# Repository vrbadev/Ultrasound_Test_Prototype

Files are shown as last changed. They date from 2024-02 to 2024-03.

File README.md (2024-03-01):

# MRS Project: Ultrasound Test (Prototype)
HW &amp; SW Project for feasibility assessment of accoustic localisation on board of UAVs

## HW Notes
* Project for Altium Designer 24.1.2
* Board power: +5V, fed to regulator AMS1117-3.3 with 3.3V output
* Main MCU: [STM32G030F6P6](https://www.st.com/en/microcontrollers-microprocessors/stm32g030f6.html) (or G031) running at 64MHz (PLL from HSI)
* MEMS microphone: ST [IMP23ABSU](https://www.st.com/en/mems-and-sensors/imp23absu.html) with 80kHz bandwidth ([STEVAL-MIC007V1](https://www.st.com/en/evaluation-tools/steval-mic007v1.html))
* Analog circuitry: PGA [MAX9939AUB+](https://www.analog.com/en/products/max9939.html), offers gain values 0.25 to 157 + optional multi-feedback filter (LP/HP/BP) on uncommited op-amp
* Selectable order of PGA and MFB filter (solder bridges SB2, SB4 closed for PGA -> MFB / SB1, SB3 for MFB -> PGA)
* Data output: USART1 (optionally with CTS flow control pin = SYNC pin); used with USB-UART adapter supporting baudrates >3Mbps (e.g., CH343)
* Exposed SWD programming interface (standard Nucleo ST-Link pin order)

**3D visualisation of the board**
Top view | Bottom view
:-------------------------:|:-------------------------:
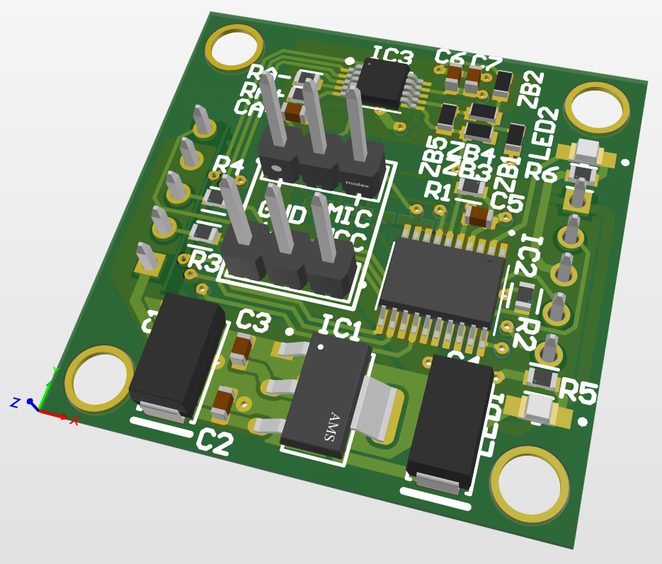
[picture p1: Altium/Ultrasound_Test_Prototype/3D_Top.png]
3D_Top
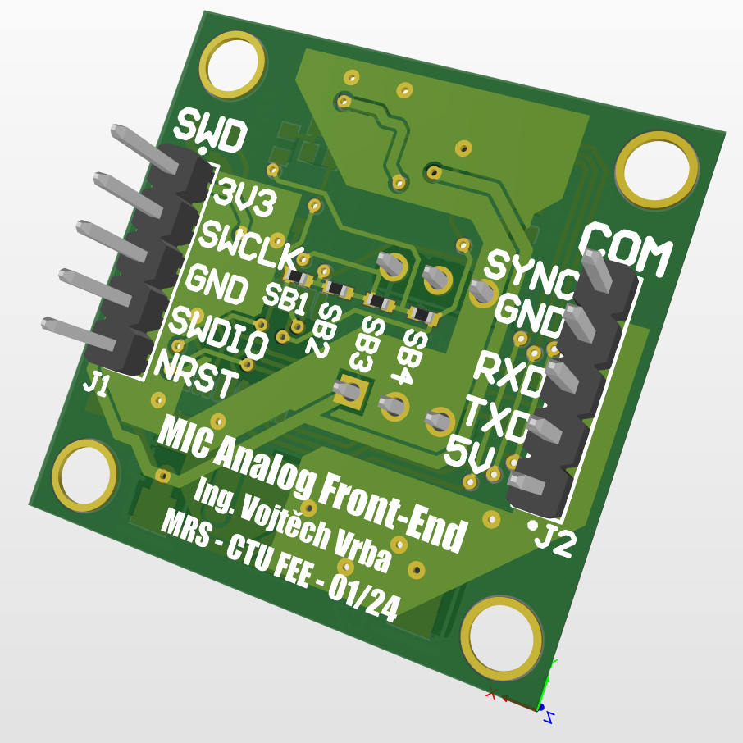
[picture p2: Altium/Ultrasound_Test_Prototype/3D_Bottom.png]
3D_Bottom
 | 

## FW Notes
* Project for STM32CubeIDE 1.14.1
* USART1 for communication running at baudrate 4Mbps
* SPI1 for PGA control (transmit only) running at 1MHz, LSB-first, 16-bit words 
* ADC channels IN0 to IN2: IN0 = direct microphone output, IN1 = PGA output, IN2 = MFB op-amp output
* ADC triggered by TIM3 for sampling frequency equal to 160kHz, oversampling x8 for noise reduction
* ADC data is transferred by DMA to RAM buffer (with size 2kB), first and second half of the buffer are processed separately in the main program loop: the ADC data is 12-bit unsigned (0-4095) stored by default in 16-bit unsigned, the main loop "compresses" every two 12-bit consequtive samples into three bytes (saves 25% of the required throughput); sampling rate 160kHz thus corresponds to only 240kBps sample data throughput
* The output data packets are transmitted via USART1 using another DMA channel, packets have total size 764B and consist of:
  - 5 delimeter bytes (0xFF) for packet start alignment,
  - 1 byte for selected PGA gain (uint8, values 0 to 9) + 1 byte for selected PGA offset (int8, values -15 to +15) + 1 byte for selected ADC channel (uint8, values 0 to 2),
  - 4 bytes for incremental packet ID (uint32),
  - 750 bytes for the 500 compressed 16-bit samples,
  - 2 dummy bytes for packet size alignment to 32-bit multiples
* Accepts USART commands for settings management:
  - `S0`/`S1` for PGA shutdown disable/enable,
  - `M0`/`M1` for PGA self-measurement disable/enable,
  - `G0` to `G9` for PGA gain selection (corresponding to 1, 10, 20, 30, 40, 60, 80, 120, 157, 0.25 gains),
  - `O+0`/`O-0` to `O+15`/`O-15` for internal PGA offset correction (+/- signed, corresponding to 0.0, 1.3, 2.5, 3.8, 4.9, 6.1, 7.3, 8.4, 10.6, 11.7, 12.7, 13.7, 14.7, 15.7, 16.7, 17.6 mV),
  - `C0` to `C2` for ADC channel selection (CH0, CH1 or CH2)

## SW Notes
* Python3 script which uses Tkinter + matplotlib for real-time visualisation of the ADC measurement: shows signal + FFT amplitude spectrum, provides simple GUI for selection of PGA gain, PGA offset and ADC channel
* Python ROS1 node which unpacks and publishes topic with the raw ADC data, automatically adjusts the PGA gain in case of saturation of the sampled analog signal

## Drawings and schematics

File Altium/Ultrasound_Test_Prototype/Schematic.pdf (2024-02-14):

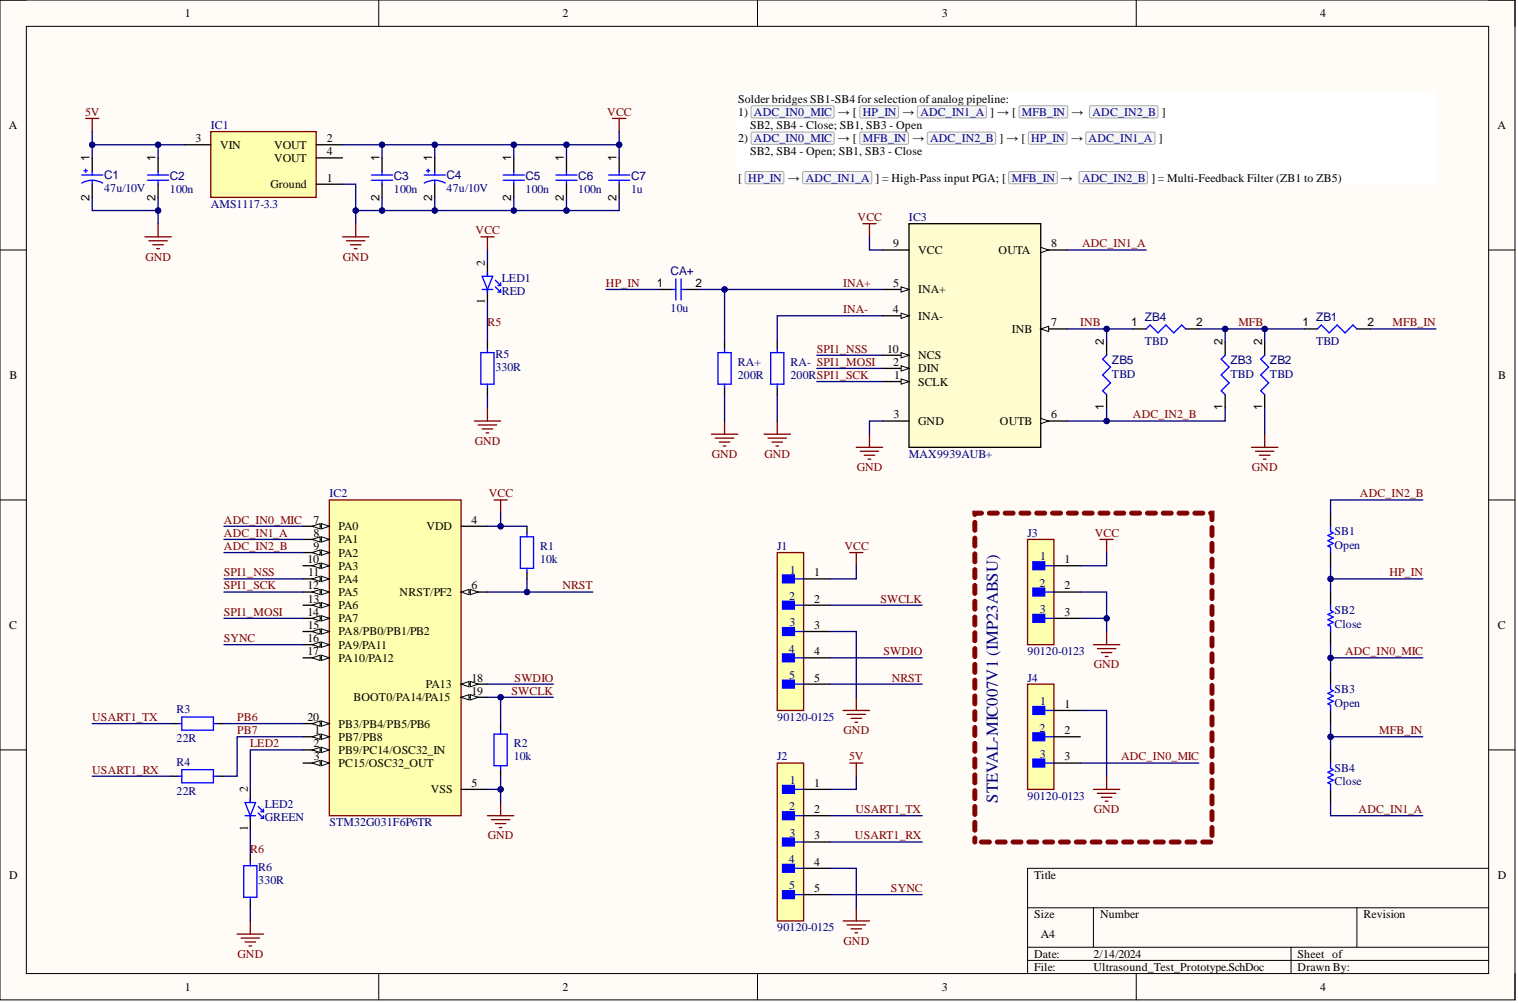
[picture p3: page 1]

Solder bridges SB1-SB4 for selection of analog pipeline:
1) ADC_IN0_MIC → [ HP_IN → ADC_IN1_A ] → [ MFB_IN → ADC_IN2_B ]
SB2, SB4 - Close; SB1, SB3 - Open
2) ADC_IN0_MIC → [ MFB_IN → ADC_IN2_B ] → [ HP_IN → ADC_IN1_A ]
SB2, SB4 - Open; SB1, SB3 - Close

[ HP_IN → ADC_IN1_A ] = High-Pass input PGA; [ MFB_IN → ADC_IN2_B ] = Multi-Feedback Filter (ZB1 to ZB5)

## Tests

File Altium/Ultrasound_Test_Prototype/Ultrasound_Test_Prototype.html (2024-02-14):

Reporting Options

# File in Newer Format

Date | : | 30.01.2024
Time | : | 13:48:40
Filename | : | C:\Users\Public\Documents\Altium\Ultrasound_Test_Prototype\Ultrasound_Test_Prototype.PrjPcb

Version | Warning

Release 23.10

CAUTION - This project contains rules defined using the Constraint Manager. You are seeing this message for two possible reasons. Firstly, this is an older version of the software that does not support this feature, in which case design rules will fall back to being presented as standard, query-based rules. If you save the PCB project in this older version of Altium Designer, all Constraint Manager data structure information will be lost. Secondly, if this software version does support the feature, then you currently don't have the level of Altium Designer Software Subscription (Pro/Enterprise) to be able to edit constraints using the Constraint Manager, in which case it will present rules in view only mode.

This file was generated by a later version of the software

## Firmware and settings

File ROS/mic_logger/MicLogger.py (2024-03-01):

#!/usr/bin/env python

import rospy
from mic_logger.msg import ADCPacketRaw

import serial
import numpy as np
import time


PGA_GAINS = np.array([1, 10, 20, 30, 40, 60, 80, 120, 157, 0.25], dtype=float)
PGA_OFFSETS = np.array([0.0, 1.3, 2.5, 3.8, 4.9, 6.1, 7.3, 8.4, 10.6, 11.7, 12.7, 13.7, 14.7, 15.7, 16.7, 17.6], dtype=float)

def search_sequence(arr, seq):
    arr = np.array(arr) if isinstance(arr, list) else arr
    seq = np.array(seq) if isinstance(seq, list) else seq
    Na, Nseq = arr.size, seq.size
    r_seq = np.arange(Nseq)
    M = (arr[np.arange(Na-Nseq+1)[:,None] + r_seq] == seq).all(1)
    if M.any() > 0:
        return np.where(np.convolve(M,np.ones((Nseq),dtype=int))>0)[0]
    else:
        return []
    

class MicLogger():
    def __init__(self):
        self.node = rospy.init_node("mic_logger")

        self.com_port = rospy.get_param("~com_port")
        self.com_baud = int(rospy.get_param("~com_baud"))
        self.com_cts = rospy.get_param("~com_cts")
        self.pga_gain = rospy.get_param("~pga_gain")
        self.pga_offset = rospy.get_param("~pga_offset")
        self.adc_channel = rospy.get_param("~adc_channel")
        self.adc_freq = rospy.get_param("~adc_freq")
        self.adc_samples_per_packet = rospy.get_param("~adc_samples_per_packet")
        self.adc_delim_seq = rospy.get_param("~adc_delim_seq")
        self.gain_adjustment_period = rospy.get_param("~gain_adjustment_period")
        self.settings_print_period = rospy.get_param("~settings_print_period")

        self.total_packet_bytes = len(self.adc_delim_seq) + 7 + int((2 * 3 * self.adc_samples_per_packet) // 4) + 2

        self.pub = rospy.Publisher("/mic_logger_data", ADCPacketRaw, queue_size=1)
    
    def get_cmd_pga_gain(self):
        g_index = np.argmin(np.abs(PGA_GAINS - self.pga_gain))
        self.pga_gain = PGA_GAINS[g_index]
        g = "G%d\n" % g_index
        return g.encode("ascii")

    def get_cmd_pga_offset(self):
        o_index = np.argmin(np.abs(PGA_OFFSETS - abs(self.pga_offset)))
        self.pga_offset = (1 if self.pga_offset >= 0 else -1) * PGA_OFFSETS[o_index]
        o = "O" + ("+" if self.pga_offset >= 0 else "-") + "%d\n" % o_index
        return o.encode("ascii")
    
    def get_cmd_adc_channel(self):
        c_index = min(2, max(0, self.adc_channel))
        c = "C%d\n" % c_index
        return c.encode("ascii")
    
    def set_pga_gain(self, com):
        cmd_gain = self.get_cmd_pga_gain()
        com.write(cmd_gain)
        com.flush()
        rospy.loginfo("[MicLogger] Sent CMD to set PGA gain: " + str(cmd_gain))

    def set_pga_offset(self, com):
        cmd_offset = self.get_cmd_pga_offset()
        com.write(cmd_offset)
        com.flush()
        rospy.loginfo("[MicLogger] Sent CMD to set PGA offset: " + str(cmd_offset))

    def set_adc_channel(self, com):
        cmd_channel = self.get_cmd_adc_channel()
        com.write(cmd_channel)
        com.flush()
        rospy.loginfo("[MicLogger] Sent CMD to set ADC channel: " + str(cmd_channel))

    def run(self):
        rospy.loginfo("[MicLogger] Launch settings: ADC channel=%d, PGA gain=%.2f, PGA offset=%.1f" % (self.adc_channel, self.pga_gain, self.pga_offset))

        rospy.loginfo("[MicLogger] Opening COM: port=%s, baud=%d" % (self.com_port, self.com_baud))

        open_com = lambda: serial.Serial(self.com_port, baudrate=self.com_baud, timeout=1, dsrdtr=self.com_cts)
        rate = rospy.Rate(1)
        while not rospy.is_shutdown():
            try:
                com = open_com()
                break
            except Exception as e:
                rospy.logwarn("[MicLogger] Failed to open COM port: " + str(e))
                rate.sleep()

        rospy.loginfo("[MicLogger] COM port opened.")

        self.set_pga_gain(com)
        rate.sleep()
        self.set_pga_offset(com)
        rate.sleep()
        self.set_adc_channel(com)
        rate.sleep()

        pga_gain_id = 0xFF
        pga_offset_id = 0xFF
        adc_channel_id = 0xFF
        packet_id = -1

        last_print_time = time.time()
        print_period_adc_data_max = 0x0000
        print_period_adc_data_min = 0xFFFF
        print_period_adc_data_sum = 0.0
        print_period_adc_data_cnt = 0
        print_period_adc_data_bytes = 0

        last_adjust_time = time.time()
        adjust_period_adc_data_max = 0x0000
        adjust_period_adc_data_min = 0xFFFF
        adjust_period_adc_data_sum = 0.0
        adjust_period_adc_data_cnt = 0

        prev_lost = False
        
        cons_sat_cnt = 0

        while not rospy.is_shutdown():
            data_raw = com.read(self.total_packet_bytes)
            data = np.frombuffer(data_raw, dtype=np.uint8)
            if len(data) > 0:
                seq_pos = search_sequence(data, self.adc_delim_seq)
                if len(seq_pos) == 0:
                    rospy.logwarn("[MicLogger] Delimeter sequence not found in the data!")
                    continue
                elif len(seq_pos) == len(self.adc_delim_seq) and seq_pos[0] > 0:
                    rospy.logwarn("[MicLogger] Lost %d bytes after #%d, aligning to delimeter sequence at pos %d" % (self.total_packet_bytes - seq_pos[0], packet_id, seq_pos[0]))
                    packet_id = -1
                    data = np.frombuffer(com.read(int(seq_pos[0])), dtype=np.uint8)
                    prev_lost = True
                else:
                    pga_gain_id = data[5]
                    pga_offset_id = np.frombuffer(data_raw[6:7], dtype=np.int8)
                    adc_channel_id = data[7]
                    packet_id = np.frombuffer(data_raw[8:12], dtype=np.uint32)
                    data = data[len(self.adc_delim_seq)+7:-2]
                
                if packet_id >= 0 and pga_gain_id <= 9 and abs(pga_offset_id) <= 15 and adc_channel_id <= 2:
                    print_period_adc_data_bytes += len(data)
                    new_adc_data = np.zeros(self.adc_samples_per_packet, dtype=np.uint16)
                    j = 0
                    for i in range(0, len(data), 3):
                        if i+1 < len(data):
                            new_adc_data[j] = data[i] | ((data[i+1] & 0x0F) << 8)
                            j += 1
                        if i+2 < len(data):
                            new_adc_data[j] = ((data[i+1] & 0xF0) << 4) | data[i+2]
                            j += 1

                    adc_data_min = new_adc_data.min()
                    adc_data_max = new_adc_data.max()
                        
                    msg = ADCPacketRaw()
                    msg.ros_stamp = rospy.Time.now()
                    msg.packet_id = int(packet_id)
                    msg.pga_gain = float(PGA_GAINS[pga_gain_id])
                    msg.pga_offset = float((-1 if pga_offset_id < 0 else 1) * PGA_OFFSETS[abs(pga_offset_id)])
                    msg.adc_channel = adc_channel_id
                    msg.adc_data = new_adc_data[:j]
                    self.pub.publish(msg)

                    if self.settings_print_period >= 0:
                        print_period_adc_data_max = max(print_period_adc_data_max, adc_data_max)
                        print_period_adc_data_min = min(print_period_adc_data_min, adc_data_min)
                        print_period_adc_data_sum += new_adc_data.sum()
                        print_period_adc_data_cnt += j

                        if self.settings_print_period > 0 and time.time() >= last_print_time + self.settings_print_period:
                            diff_time = time.time() - last_print_time
                            print_period_adc_data_mean = print_period_adc_data_sum / print_period_adc_data_cnt
                            rospy.loginfo("[MicLogger] [#%d,G=%.2f,O=%.1f,CH%d] Received %d bytes (%d samples) in last %.3f sec -> %d B/s (%d sps); mean: %.2f; min: %d; max: %d" % (packet_id, msg.pga_gain, msg.pga_offset, adc_channel_id, print_period_adc_data_bytes, print_period_adc_data_cnt, diff_time, print_period_adc_data_bytes / diff_time, print_period_adc_data_cnt / diff_time, print_period_adc_data_mean, print_period_adc_data_min, print_period_adc_data_max))
                            last_print_time = time.time()
                            print_period_adc_data_bytes = 0
                            print_period_adc_data_max = 0x0000
                            print_period_adc_data_min = 0xFFFF
                            print_period_adc_data_sum = 0.0
                            print_period_adc_data_cnt = 0


                    sel_gain_id = np.argmin(np.abs(PGA_GAINS - self.pga_gain))
                    if sel_gain_id == pga_gain_id and self.gain_adjustment_period >= 0:
                        adjust_period_adc_data_max = max(adjust_period_adc_data_max, adc_data_max)
                        adjust_period_adc_data_min = min(adjust_period_adc_data_min, adc_data_min)
                        adjust_period_adc_data_sum += new_adc_data.sum()
                        adjust_period_adc_data_cnt += j

                        if (self.gain_adjustment_period > 0 and time.time() >= last_adjust_time + self.gain_adjustment_period) or self.gain_adjustment_period == 0.0:
                            adjust_period_adc_data_mean = adjust_period_adc_data_sum / adjust_period_adc_data_cnt
                            #rospy.loginfo("sum=%f cnt=%f mean=%f min=%f max=%f" % (adjust_period_adc_data_sum, adjust_period_adc_data_cnt, adjust_period_adc_data_mean, adjust_period_adc_data_min, adjust_period_adc_data_max))
                            dist = max(abs(adjust_period_adc_data_mean - adjust_period_adc_data_min), abs(adjust_period_adc_data_mean - adjust_period_adc_data_max))
                            if dist > 1800:
                                new_gain_id = max(0, pga_gain_id - 1)
                                if pga_gain_id != new_gain_id:
                                    rospy.loginfo("[MicLogger] The ADC values are too high, decreasing gain from %.2f to %.2f" % (PGA_GAINS[pga_gain_id], PGA_GAINS[new_gain_id]))
                                    self.pga_gain = PGA_GAINS[new_gain_id]
                                    self.set_pga_gain(com)
                            elif dist < 200:
                                new_gain_id = min(8, pga_gain_id + 1)
                                if pga_gain_id != new_gain_id:
                                    rospy.loginfo("[MicLogger] The ADC values are too low, increasing gain from %.2f to %.2f" % (PGA_GAINS[pga_gain_id], PGA_GAINS[new_gain_id]))
                                    self.pga_gain = PGA_GAINS[new_gain_id]
                                    self.set_pga_gain(com)

                            last_adjust_time = time.time()
                            adjust_period_adc_data_max = 0x0000
                            adjust_period_adc_data_min = 0xFFFF
                            adjust_period_adc_data_sum = 0.0
                            adjust_period_adc_data_cnt = 0

                    if adc_data_min == 0:
                        rospy.logwarn("[MicLogger] [#%d] Minimum value is 0 (low saturation)!" % (packet_id))
                        cons_sat_cnt += 1
                    elif adc_data_max == 4095:
                        rospy.logwarn("[MicLogger] [#%d] Maximum value is 4095 (high saturation)!" % (packet_id))
                        cons_sat_cnt += 1
                    else:
                        cons_sat_cnt = 0

                    prev_lost = False
            else:
                rospy.logwarn("[MicLogger] No data received, reopening COM port...")
                com.close()
                rate.sleep()
                com = open_com()
        
        com.close()
        rospy.loginfo("[MicLogger] COM port closed.")


if __name__ == '__main__':
    logger = MicLogger()
    logger.run()
    rospy.spin()

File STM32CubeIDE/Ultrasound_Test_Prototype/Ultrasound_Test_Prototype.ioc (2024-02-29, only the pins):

Mcu.UserName=STM32G030F6Px
PA0.Signal=ADC1_IN0
PA1.Signal=ADC1_IN1
PA13.Signal=SYS_SWDIO
PA14-BOOT0.Signal=SYS_SWCLK
PA2.Signal=ADC1_IN2
PA4.GPIO_Label=SPI1_NSS
PA4.Signal=GPIO_Output
PA5.Signal=SPI1_SCK
PA7.Signal=SPI1_MOSI
PB6.Signal=USART1_TX
PB7.Signal=USART1_RX

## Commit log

2024-02-14 Added HW files
    [Ultrasound_Test_Prototype.PcbDoc, Ultrasound_Test_Prototype.PrjPcb, Ultrasound_Test_Prototype.SchDoc]
2024-02-15 Fixed ROS params loading
    [MicLogger.py]
2024-02-15 Added COM reopening in case of no data
2024-02-29 Extended TX buffer with ID, gain, offset, ADC channel & Python GUI controls
2024-03-01 Settable/disablable print and gain adj. periods
